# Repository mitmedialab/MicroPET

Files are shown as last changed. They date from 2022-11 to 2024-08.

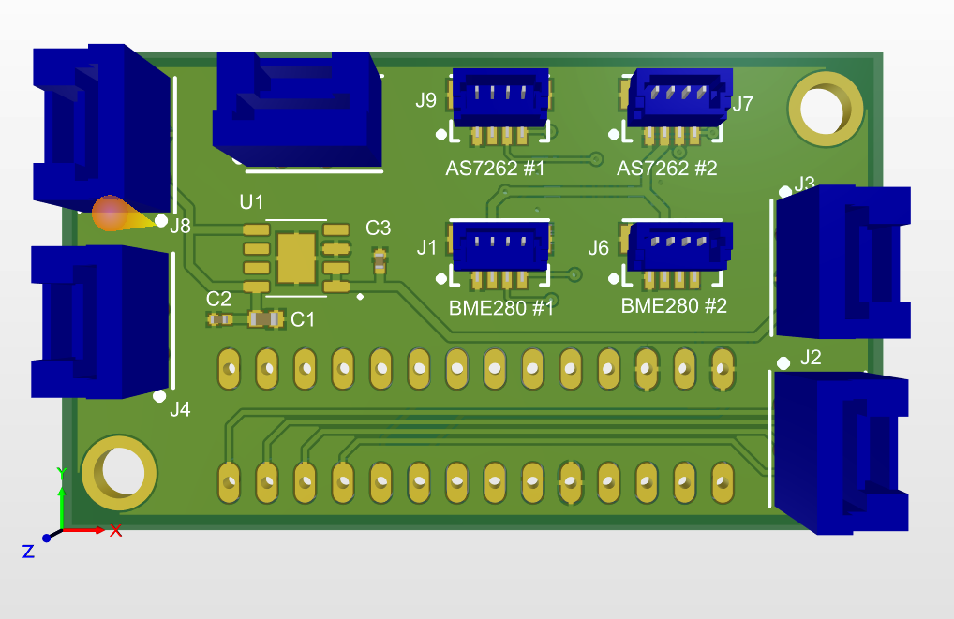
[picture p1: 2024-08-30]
Electronics/Sensor Board/MicroPET Sensor Board - Rev C - rendering.png

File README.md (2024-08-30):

# MicroPET
###  From Development and flight-testing of a modular autonomous cultivation system for biological plastics upcycling aboard the International Space Station

Xin Liu1*, Pat Pataranutaporn1*, Benjamin Fram2, Allison Z. Werner3*, Sunanda Sharma5, Nicholas P. Gauthier4, Erika Erickson3, Patrick Chwalek1, Kelsey J. Ramirez3, Morgan A. Ingraham3, Natasha P. Murphy3, Krista A Ryon6, Braden T Tierney6, Gregg T. Beckham3, Christopher E. Mason7, Ariel Ekblaw1

[1] MIT Media Lab	, Massachusetts Institute of Technology, Cambridge, MA 
[2] Harvard Medical School, Department of Systems Biology, Boston, MA 
[3] Renewable Resources and Enabling Sciences Center, National Renewable Energy Laboratory, Golden, CO 
[4] Department of Data Sciences, Dana-Farber Cancer Institute, Boston, MA
[5] Space Exploration Initiative, Massachusetts Institute of Technology, Cambridge, MA
[6] Weill Cornell Medical College, Cornell University, New York, NY
[7] Department of Physiology and Biophysics, Weill Cornell Medicine, New York, NY

Correspondence: xxxxxxin@mit.edu, patpat@mit.edu, allison.werner@nrel.gov

### Abstract
Cultivation of microorganisms in space has enormous potential to enable in-situ resource utilization (ISRU), but spaceflight infrastructure for growing microorganisms without resource-intensive astronaut support is lacking. Here, we develop and validate an autonomous payload, termed the Modular Open Biological Platform (MOBP), for enzymatic reactions and microbial cultivation with fully programmable serial passaging and sample preservation. The MOBP is a compact, modular bioreactor system that allows for automatic media transfers and precise data monitoring from integrated sensors. The payload enables serial sample collection and storage for terrestrial analysis, including RNA and DNA sequencing and proteomics. We designed two experiments for validation of the MOBP aboard the International Space Station (ISS) with the application of upcycling the ubiquitous plastic poly(ethylene terephthalate) (PET). In the enzymatic experiment, PET is depolymerized by the enzyme PETase to terephthalate (TPA), which can then be polymerized back into virgin quality PET. In the cell-based experiment, TPA is converted to β-ketoadipate (βKA) by an engineered Pseudomonas putida KT2440 bacterium. βKA can be polymerized into a nylon-6,6 analog with improved properties for use in the production of a variety of materials, including high-performance textiles and molded parts including air intake manifolds, electro-insulation elements and hinges, thus demonstrating plastics upcycling. We posit our modular open system will enable increased realization of synthetic biology experiments and applications in spaceflight that will ultimately enable ISRU and plastics upcycling during space travel.

### Keywords
In-situ resource utilization, plastics upcycling, biomanufacturing

### Repository
All code and resources for the MOBP (Modular Open Biological Platform) are available in this GitHub repository. This includes:
- Teensy Launch Code: Teensyduino code to operate MicroPET payload
- Simulation: simulating liquid operation for MicroPET payload
- 3D printing files for the MOBP hardware
- Electronic files for the MOBP

You can access and download all these resources directly from this repository.

# Teensy Launch Code
The code provided is for a MicroPET payload using a Teensyduino microcontroller. The code includes several libraries and defines multiple functions and variables for controlling and managing the payload's experiments and sensors.

The code starts by including various libraries such as TimeLib, TimeAlarms, Wire, SPI, Adafruit_Sensor, Adafruit_BME280, Adafruit_AS726x, Adafruit_MCP23X17, and RTClib. These libraries are used to interface with different sensors and modules.

Next, there are function prototypes for 26 different experiment days, numbered from day_1 to day_26. These functions are used to execute specific experiments on each day of the payload's operation.

The experimentArray is an array of function pointers that stores the addresses of each experiment function. This allows the code to easily access and execute the desired experiment based on the current day.

The code then defines various pin mappings and addresses for different components connected to the Teensyduino, such as the base board connectors and MCP23X17 GPIO expanders.

Further in the code, there are implementations of functions for controlling motors, switching IO ports, moving liquids between different chambers, switching collection bags, taking sensor data, initializing the SD card, and saving data to files.

The loop function of the code waits for a serial start command from the user to begin the payload's experiments. Once the command is received, the code calls the day_1 function to start the first day's experiment. After each experiment, the code sets the next alarm to schedule the next experiment based on the defined delay between experiments.

There is also a function for recovering the system after an unscheduled power loss. This function checks if the system was interrupted during an experiment or if it was off for a longer time than the experiment interval. If it can resume the experiment, it sets the next alarm and continues from where it left off.

The rest of the code includes functions for reading data from sensors, saving sensor data to a file, and initializing the SD card and experimental log file. Overall, the code provides the functionality for controlling and managing the MicroPET payload, executing different experiments, collecting sensor data, and saving data to files.

### Base Board Connection
The base board connections are as follows:
- E1VA + E1PA - J10
- E1VB + E1PB - J09
- E2VA + E2PA - J12
- E2VB + E2PB - J11
- The valve board connector J1-6 are the same on the base board

### Dependencies
The code depends on the following libraries:
- TimeLib.h
- TimeAlarms.h
- Wire.h
- SPI.h
- Adafruit_Sensor.h
- Adafruit_BME280.h
- Adafruit_AS726x.h
- Adafruit_MCP23X17.h
- RTClib.h
- SD.h

### Experiment Protocols
The code defines the following experiment protocols:
- day_1()
- day_2()
- day_3()
- day_4()
- ...
- day_26()

The experiment functions are stored in an array called `experimentArray`, which is of size `TOTAL_EXPERIMENTS`.

### Global Variables
- `rtc`: RTC_PCF8523 object to interface with the RTC module.
- `experimentIndex`: uint16_t variable to keep track of the current experiment index.
- `delayTime`: unsigned long variable to store the delay time between experiments.
- `sensorValues`: uint16_t array to store the sensor values read from the AS726x sensor.
- `myFile`: File object to store data in a file.
- `expLogFile`: File object to store experimental log data in a file.
- `systemStateStructVar`: systemStateStruct object to store the system state.

### Main Functions
- `setup()`: Initializes the program by initializing variables, setting up the RTC, SD card, and IO ports, and setting the first alarm.
- `loop()`: Loops indefinitely, checking for a start command via serial communication and executing the corresponding experiment.
- `rtcInit()`: Initializes the RTC module by checking for RTC availability, adjusting the time if necessary, and calibrating the RTC.
- `grabStateFromSD()`: Reads the system state from the SD card if it exists, and returns true if successful.
- `saveStateToSD()`: Saves the system state to the SD card.
- `checkForStartSerialCommand()`: Checks for a start command via serial communication and returns true if it is received.
- `recoverSystemStart()`: Resumes system operation after an unscheduled power loss by checking for hard faults and setting up timers.
- `setNextAlarm()`: Sets the next alarm based on the current experiment index.
- `moveLiquid()`: Moves liquid from one location to another based on the experiment, origin, target, and liquid volume.
- `switchCollection()`: Switches the collection bag for a particular experiment.
- `Taking_Sensor_Data()`: Takes sensor data by reading temperature and spectral values from the BME280 and AS726x sensors.
- `saveExperimentalLog()`: Saves an experimental log message to the experiment log file.
- `init_card()`: Initializes the SD card by checking for availability, opening the save file, and writing the header if necessary.
- `initExpLogFile()`: Initializes the experiment log file by opening it and writing the header.
- `motorSensorBrdCtrl()`: Controls the motors on the sensor board based on the motor number and direction.

### Helper Functions
- `digitalClockDisplay()`: Displays the current time on the serial monitor.
- `printDigits()`: Prints digits with leading zeroes if necessary.
- `tmConvert_t()`: Converts a specified date and time to a time_t format.

### Contact
For questions or further information, please contact the corresponding authors listed above.

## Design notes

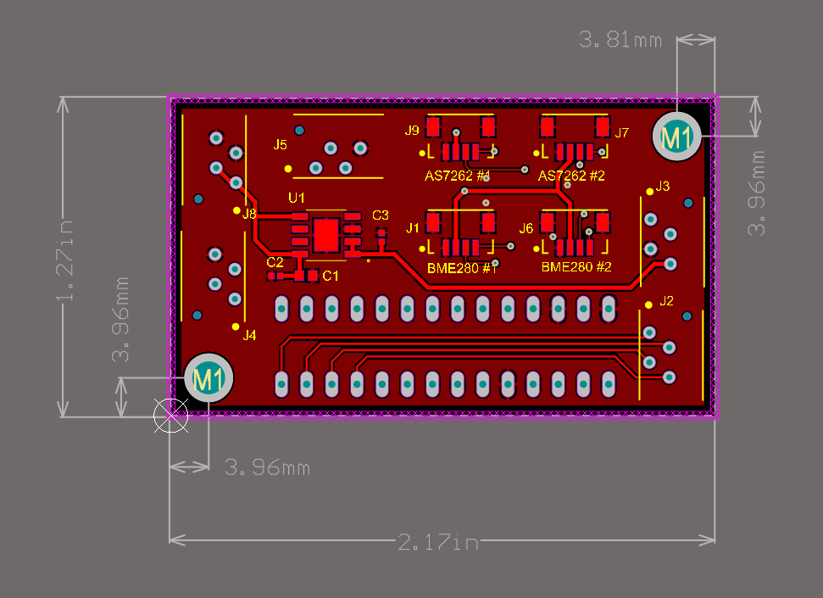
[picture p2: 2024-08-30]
Electronics/Sensor Board/MicroPET Sensor Board - Rev C.png

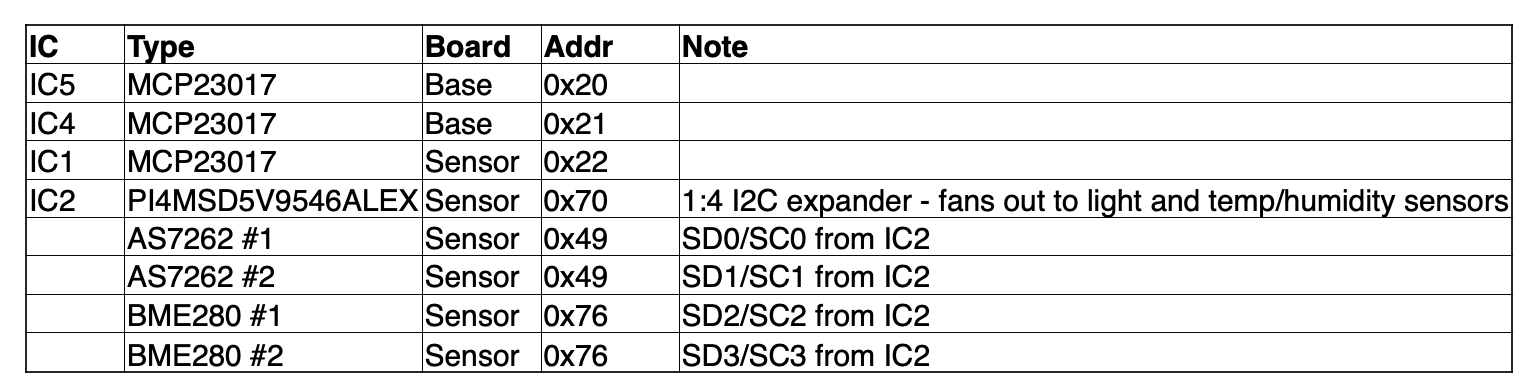
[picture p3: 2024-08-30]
Electronics/Sensor Board/MicroPET Sensor Board - Rev C - IO ports.png

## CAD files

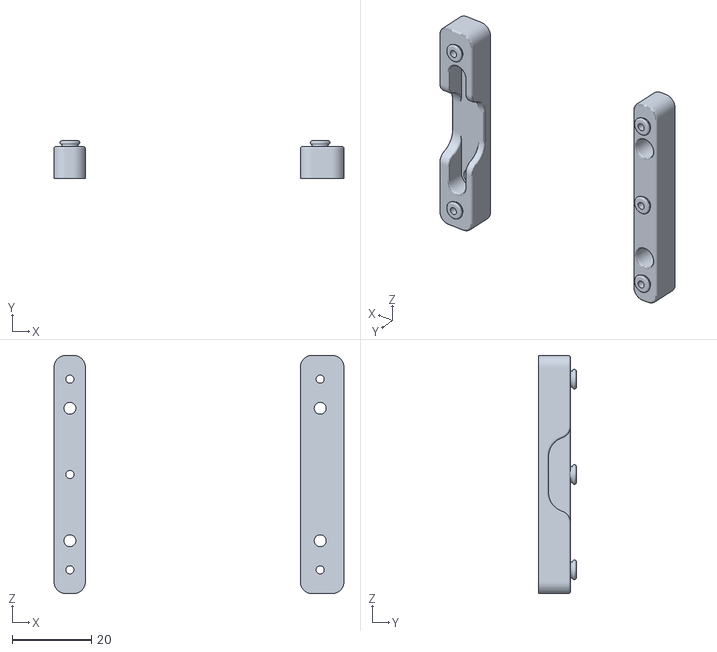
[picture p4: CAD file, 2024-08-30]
3D Printing/Bag Holder Prints/micropet_enclosure_print_001.STL
73.0 x 9.50 x 60.0

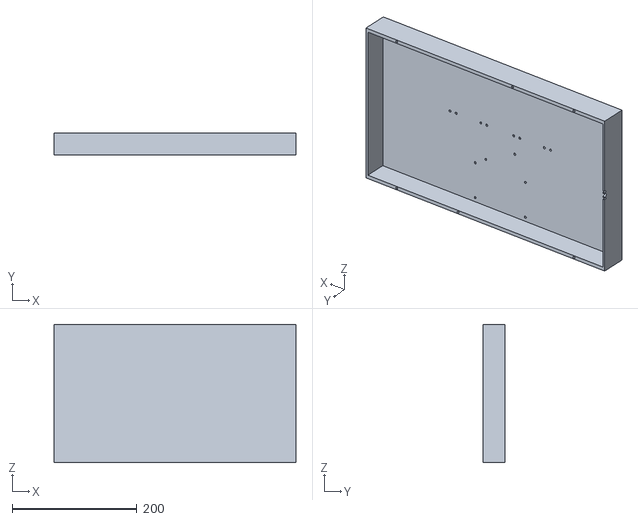
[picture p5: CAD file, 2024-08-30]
3D Printing/MicroPET_top_enclosure_twocells.stl
388.6 x 36.1 x 222.0

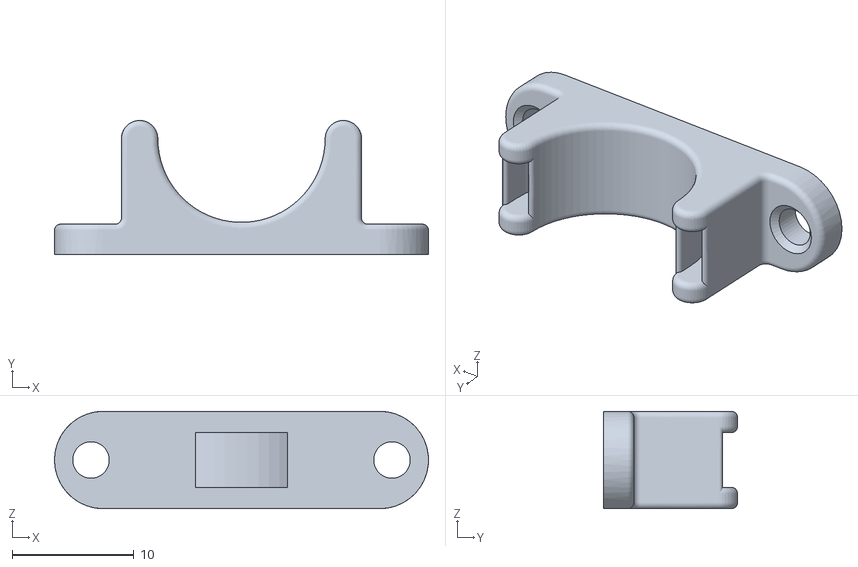
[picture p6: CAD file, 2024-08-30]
3D Printing/Bag Holder Prints/micropet_enclosure_print_004.STL
30.8 x 11.0 x 8.00

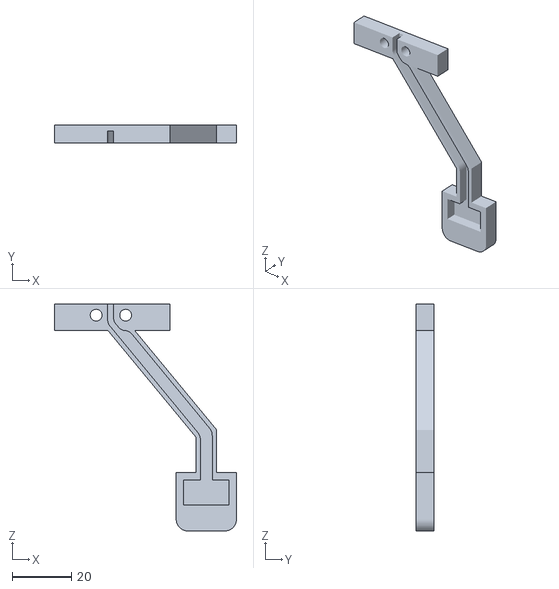
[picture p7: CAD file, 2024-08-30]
3D Printing/BioCell LED holder v5.stl
61.7 x 6.00 x 76.9

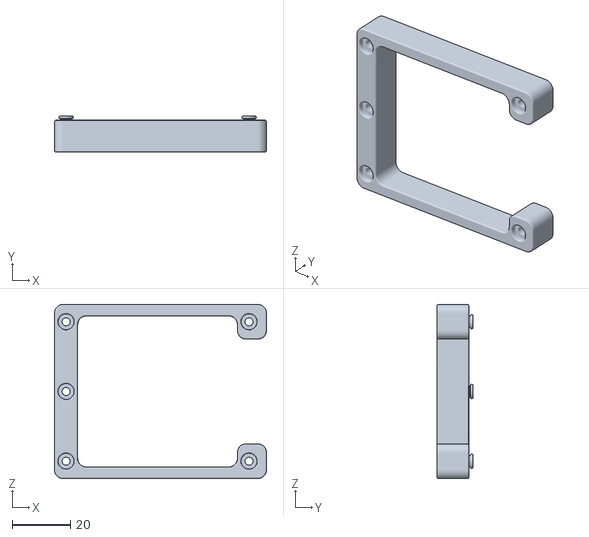
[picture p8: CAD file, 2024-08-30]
3D Printing/Bag Holder Prints/micropet_enclosure_print_002.STL
73.0 x 12.5 x 60.0

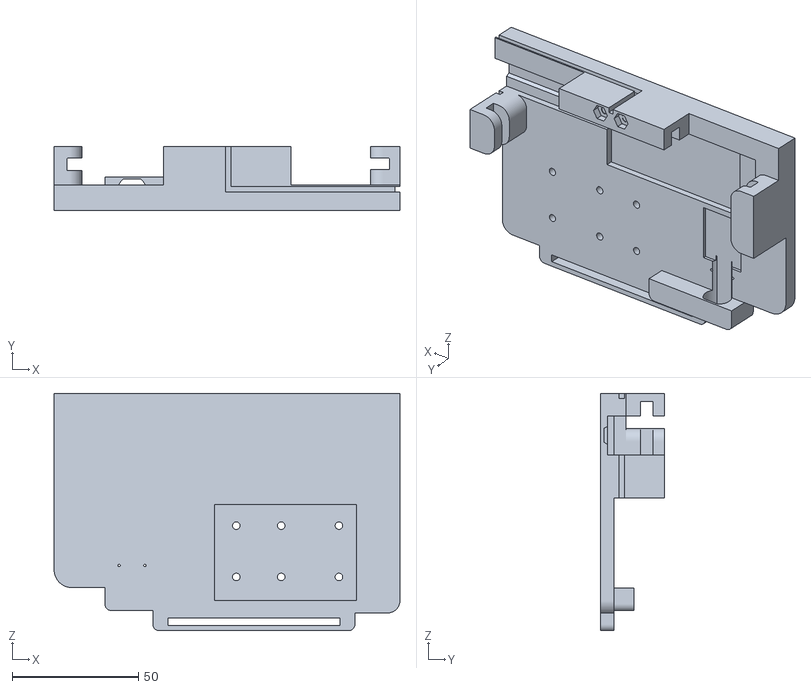
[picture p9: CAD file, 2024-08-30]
3D Printing/BioCell Final Print v5.stl
137.0 x 25.5 x 94.0

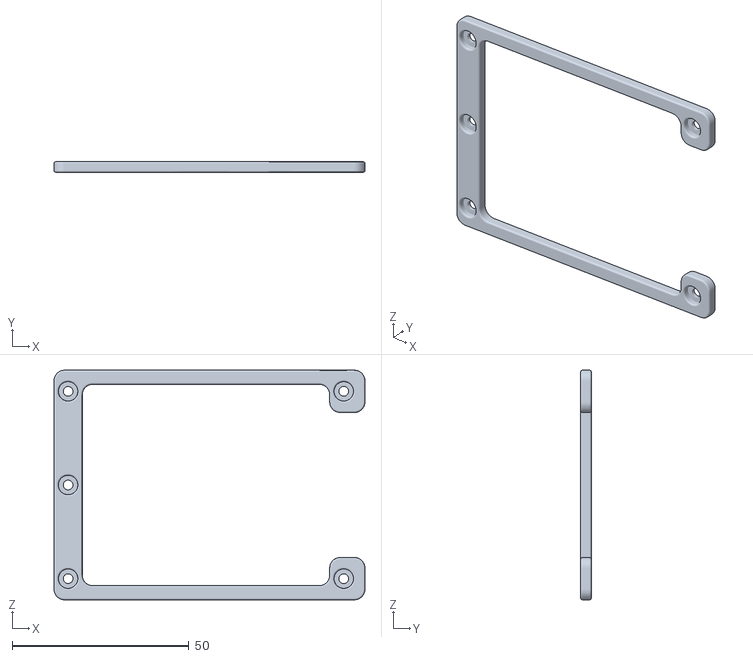
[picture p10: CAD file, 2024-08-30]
3D Printing/Bag Holder Prints/micropet_enclosure_print_009.STL
88.0 x 3.00 x 65.0

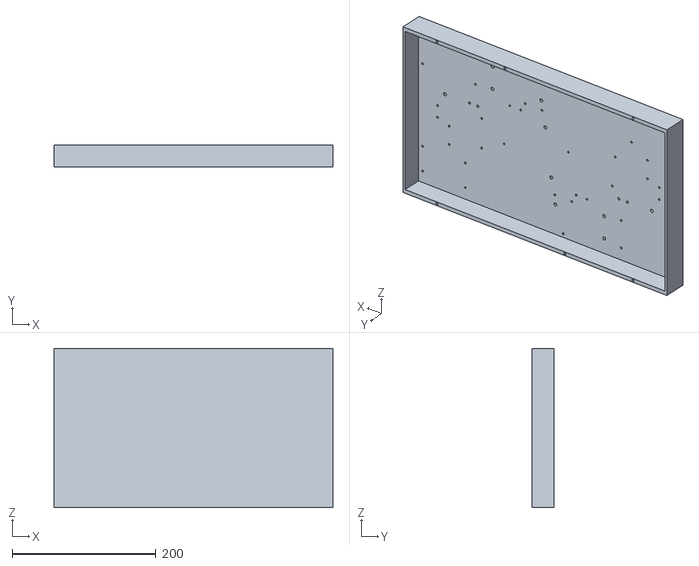
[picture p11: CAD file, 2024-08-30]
3D Printing/MicroPET_base_enclosure_01 v2.stl
388.6 x 30.4 x 222.0

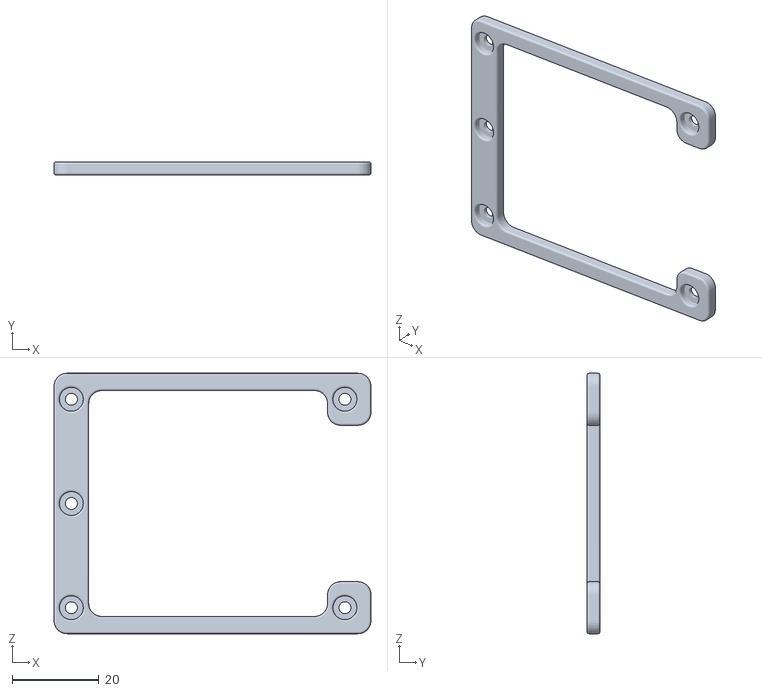
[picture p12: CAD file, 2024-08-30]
3D Printing/Bag Holder Prints/micropet_enclosure_print_003.STL
73.0 x 3.00 x 60.0

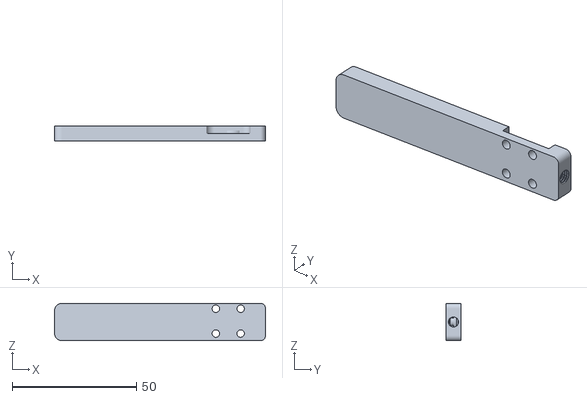
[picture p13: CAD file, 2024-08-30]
3D Printing/Revival Chip.stl
85.0 x 6.00 x 15.0

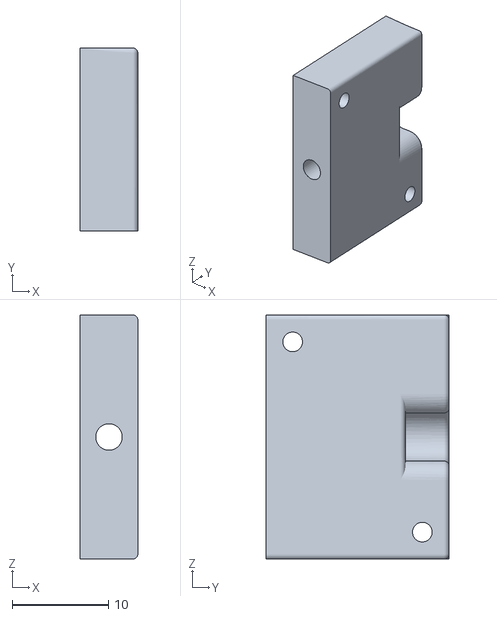
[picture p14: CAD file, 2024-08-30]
3D Printing/Bag Holder Prints/micropet_enclosure_print_006.STL
6.00 x 19.1 x 25.4

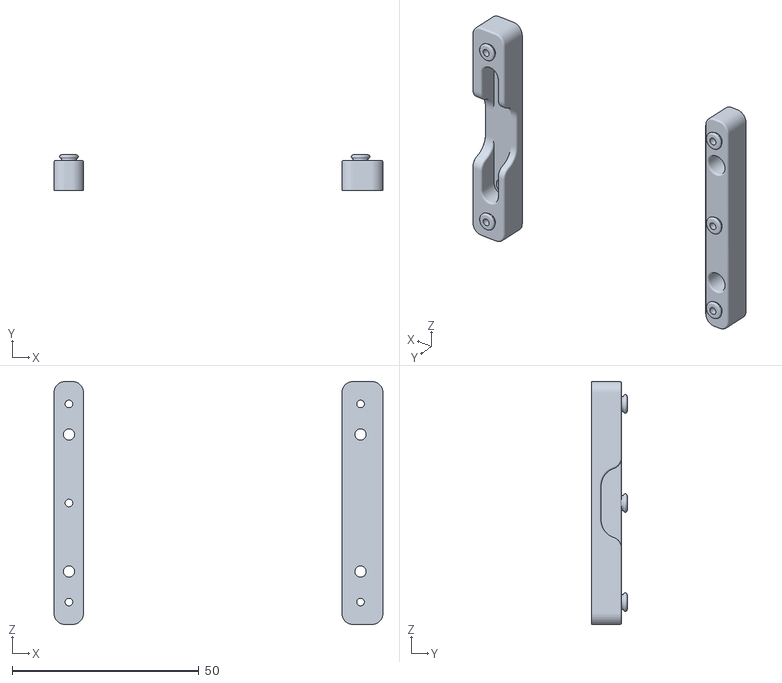
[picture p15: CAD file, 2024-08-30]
3D Printing/Bag Holder Prints/micropet_enclosure_print_007.STL
88.0 x 9.50 x 65.0

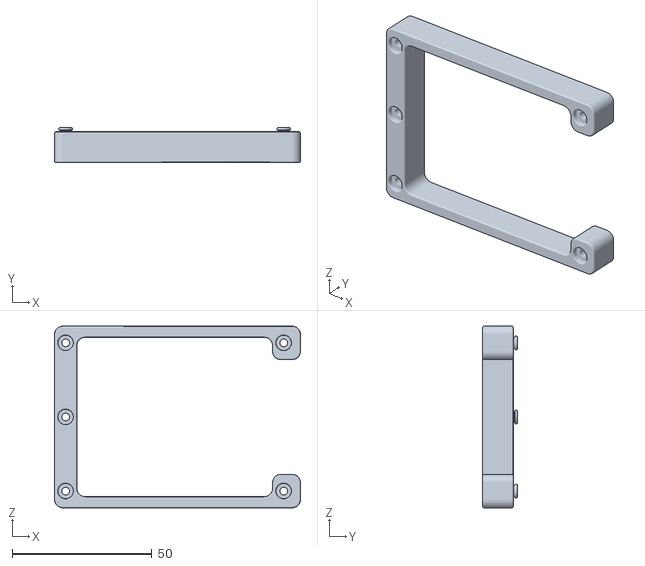
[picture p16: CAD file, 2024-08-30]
3D Printing/Bag Holder Prints/micropet_enclosure_print_008.STL
88.0 x 12.5 x 65.0

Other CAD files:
3D Printing/Bag Holder Prints/micropet_enclosure_print_005.STL
3D Printing/Bag Holder Prints/micropet_enclosure_print_010.STL

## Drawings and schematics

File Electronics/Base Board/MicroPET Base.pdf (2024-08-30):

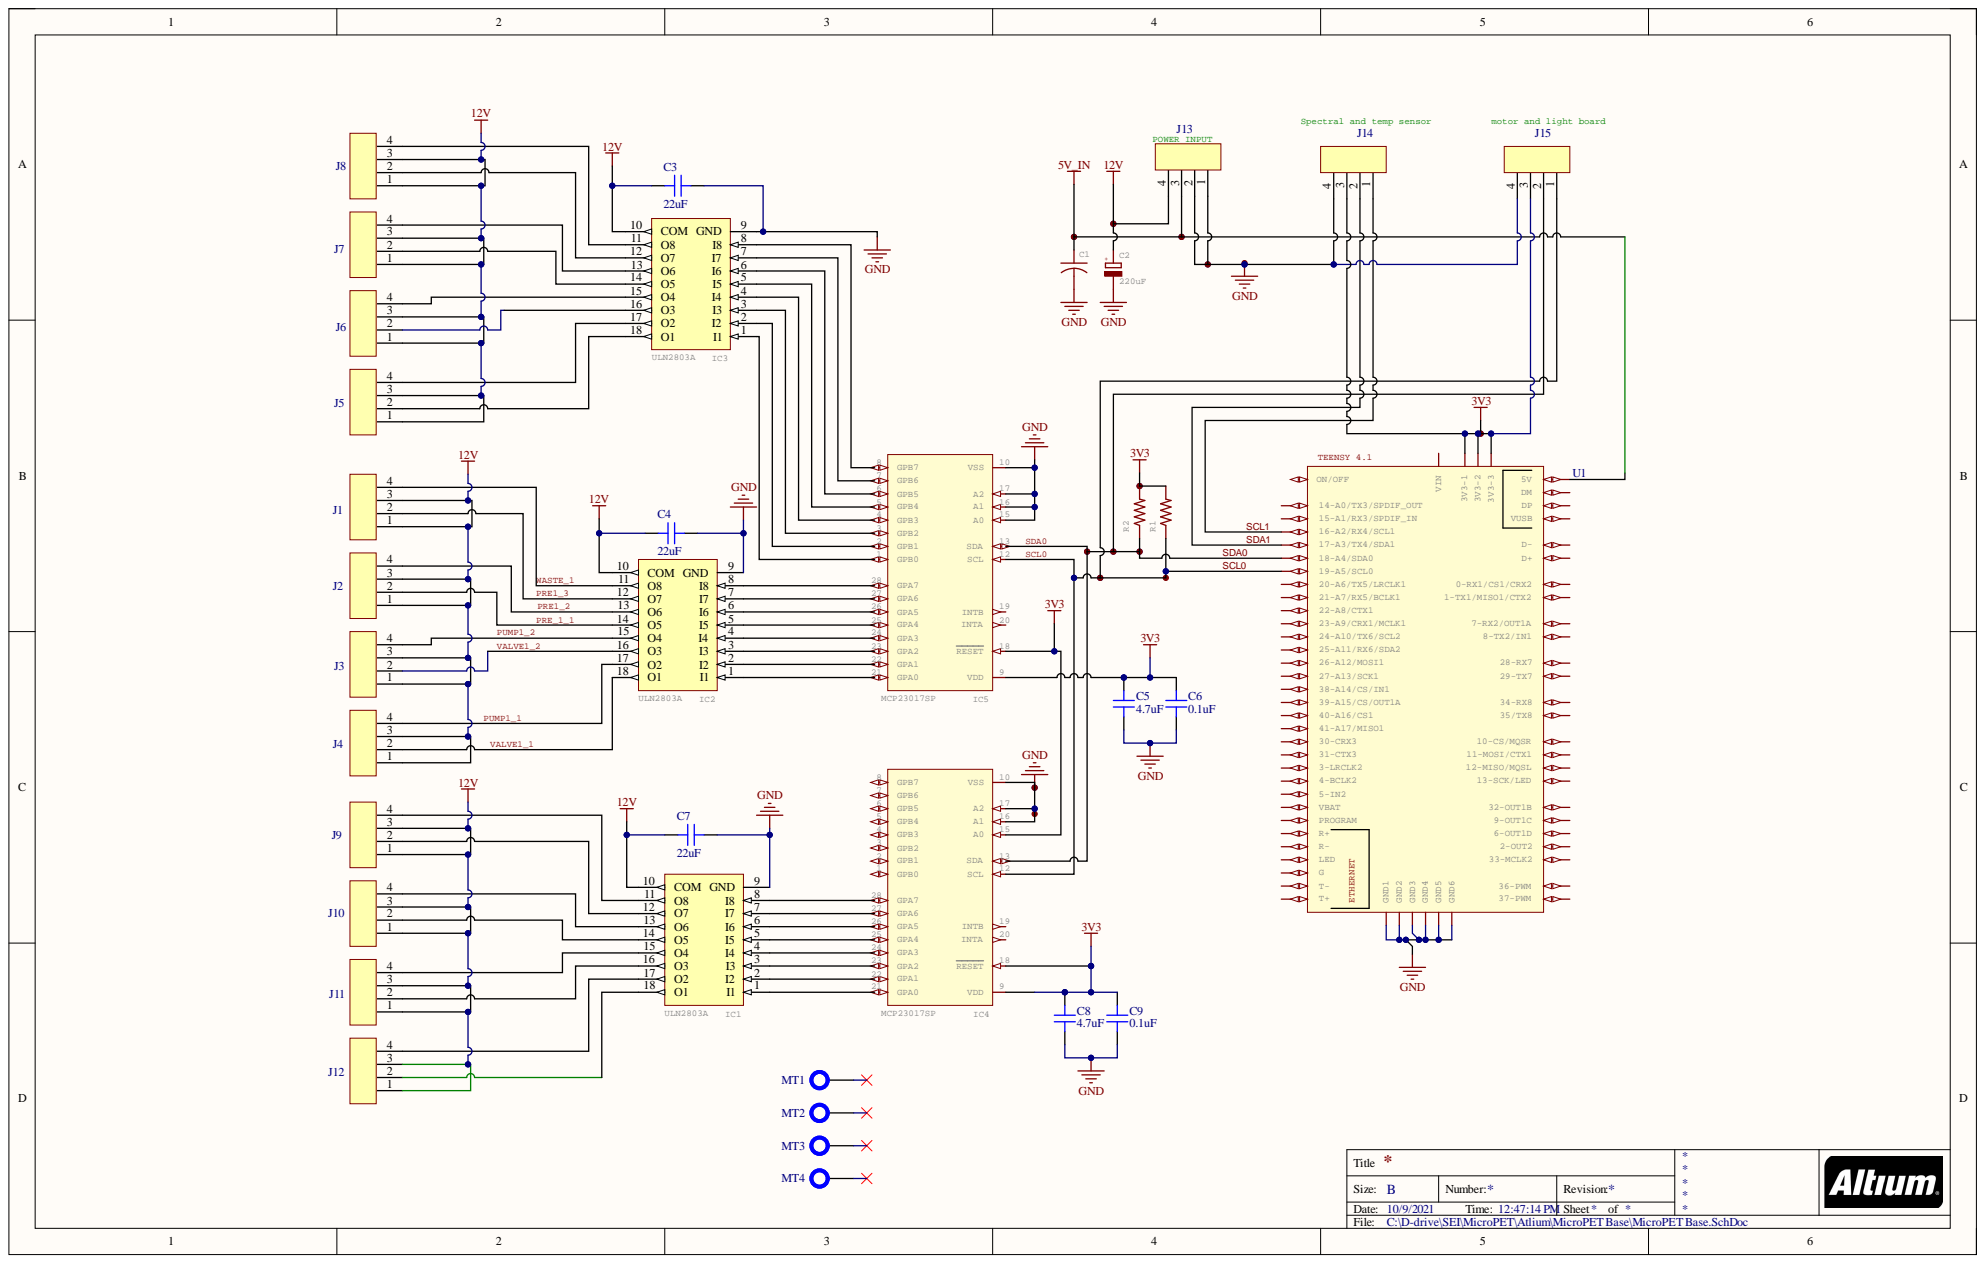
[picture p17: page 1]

3 | 12V

3 | WASTE_1
2 | | 3V3

3 | VALVE1_1

Title * | * * * * *

Size: B | Number: * | Revision: *
Date: 10/9/2021 Time: 12:47:14 PM | | Sheet * of *

C:\D-drive\SEI\MicroPET\Atlium\MicroPETBase\MicroPETBase.SchDoc

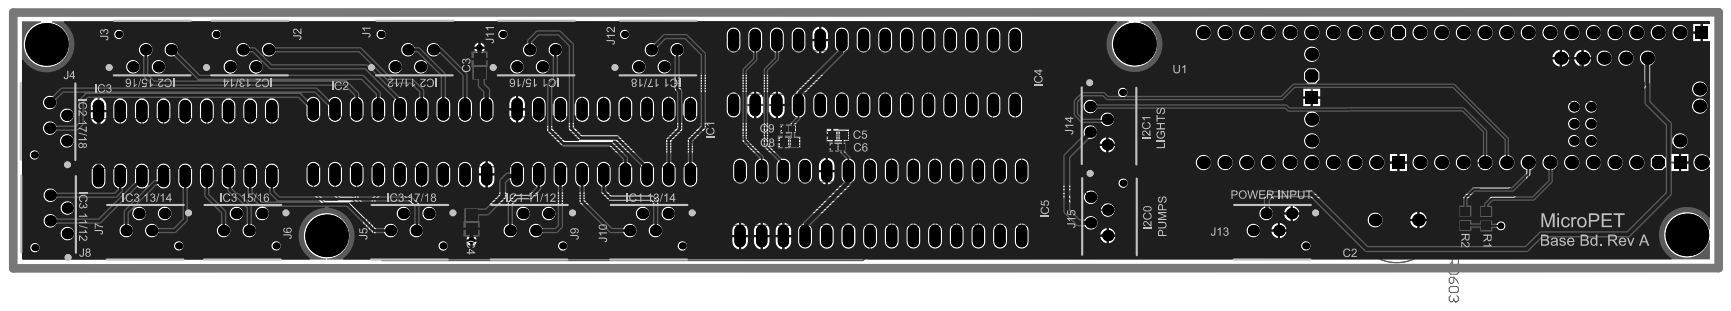
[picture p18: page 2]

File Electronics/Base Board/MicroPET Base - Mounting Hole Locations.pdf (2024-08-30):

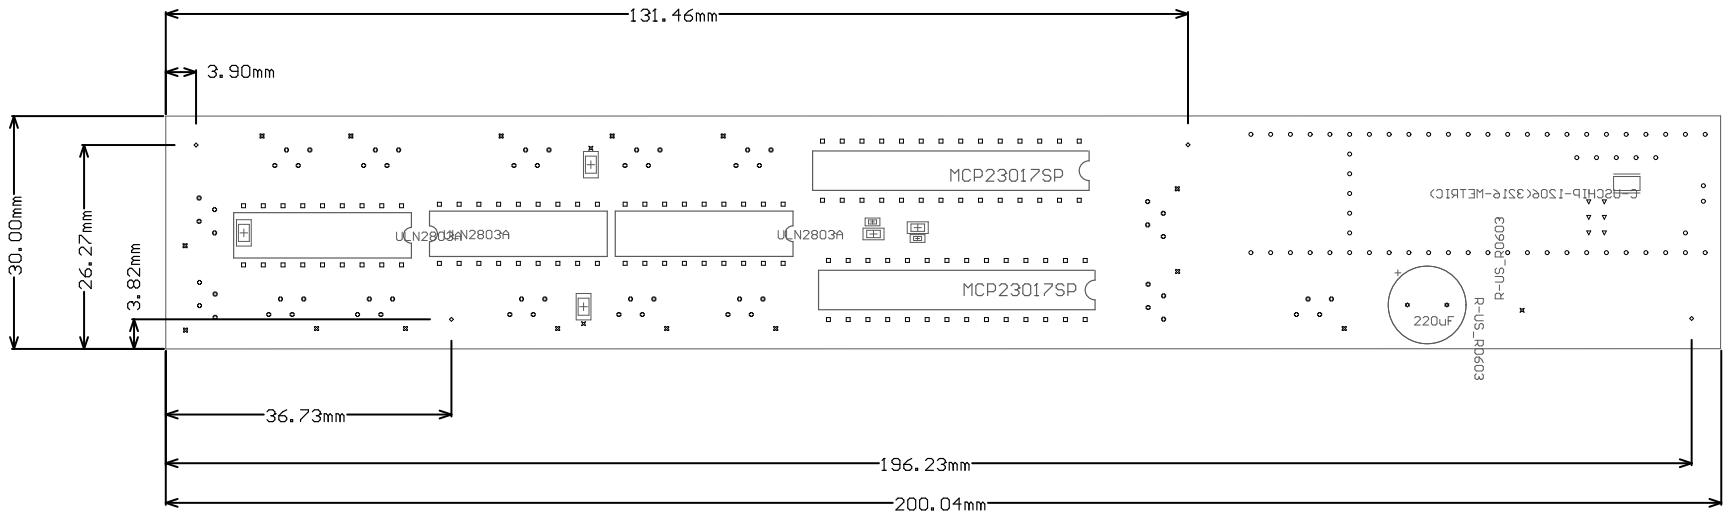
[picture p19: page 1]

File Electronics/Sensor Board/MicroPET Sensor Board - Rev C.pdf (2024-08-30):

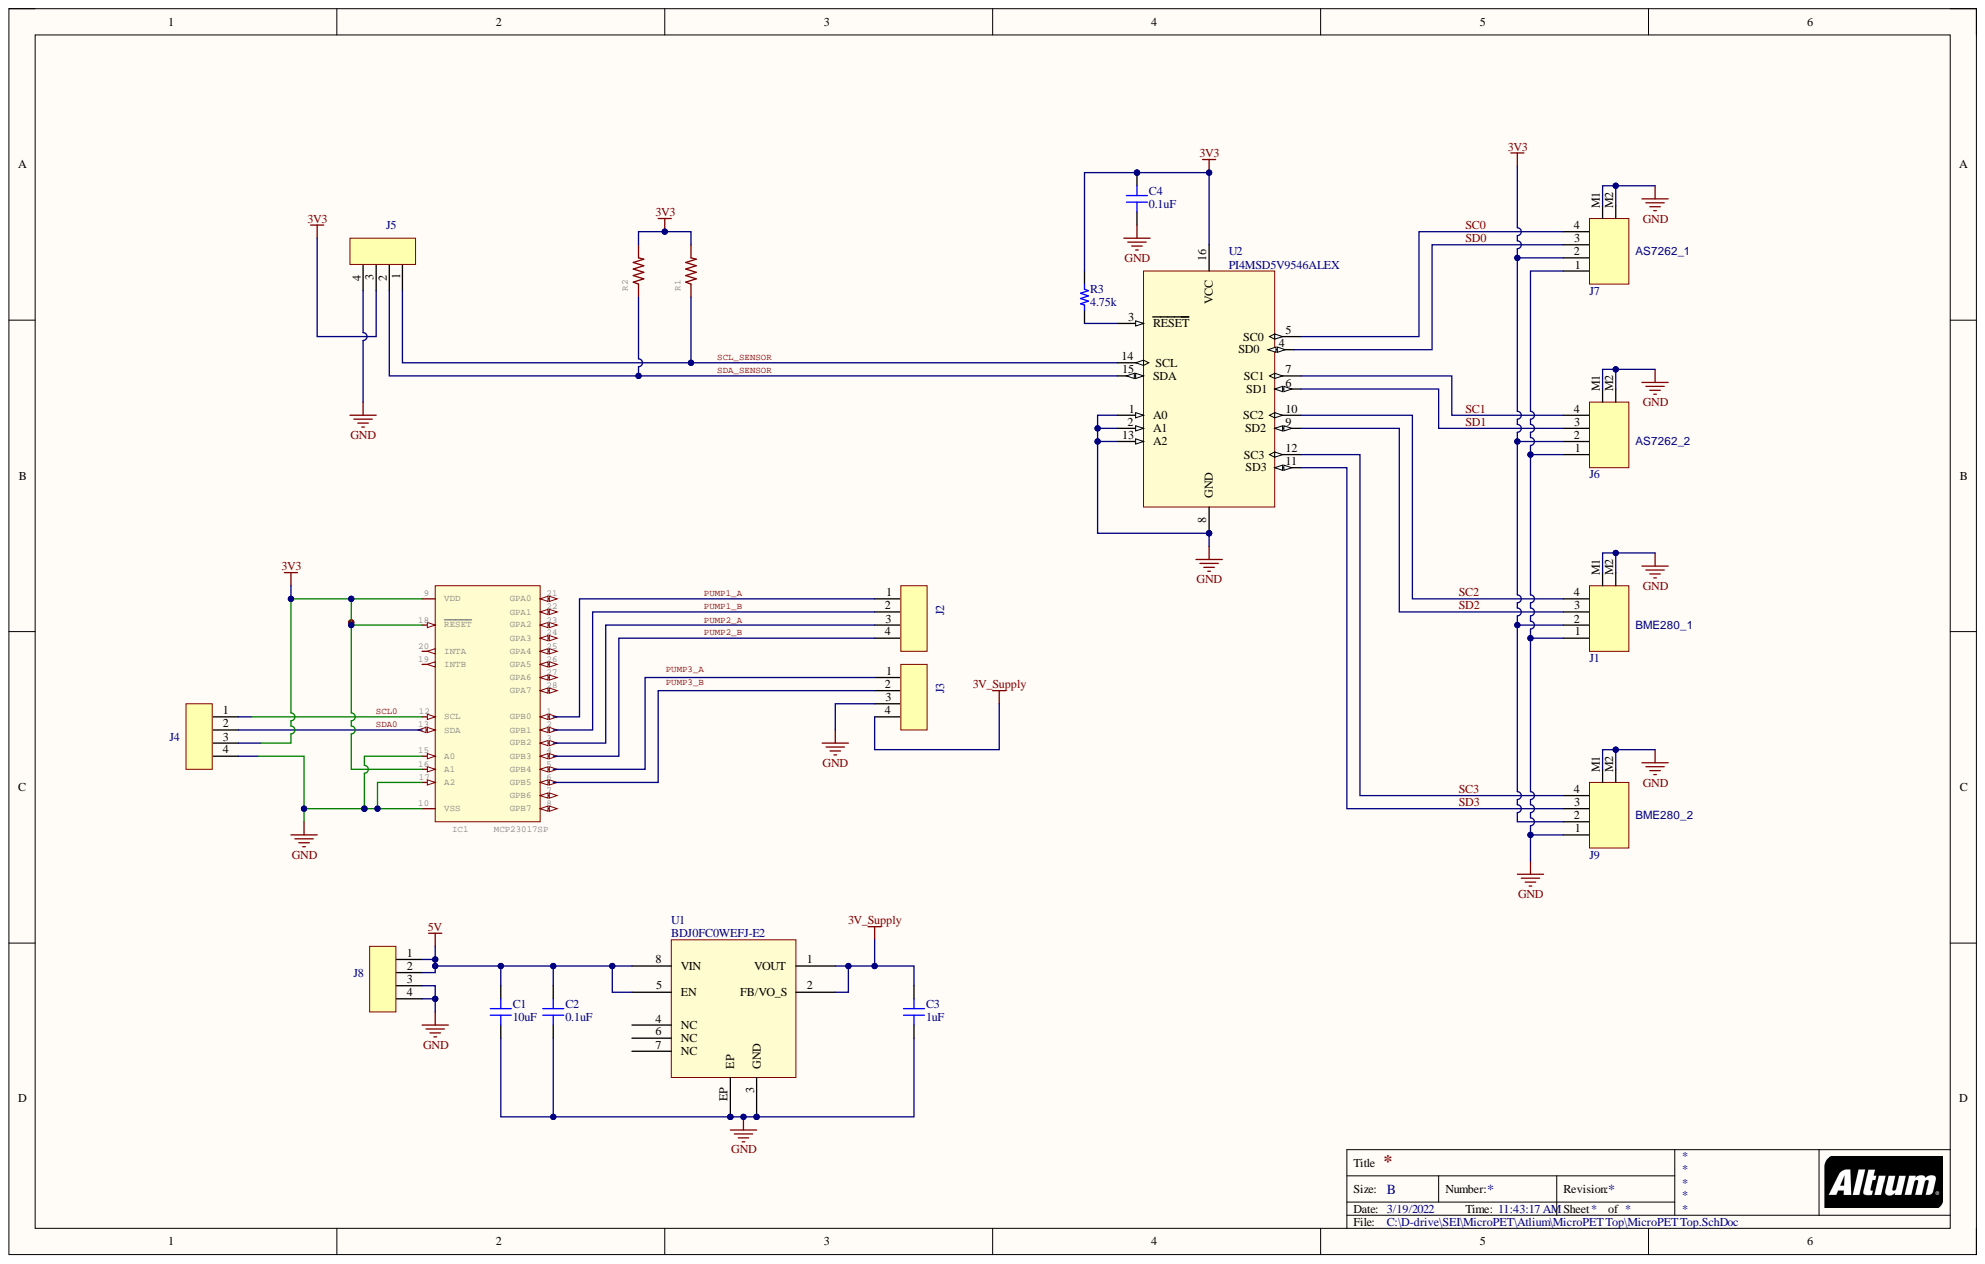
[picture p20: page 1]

RESE A 15 T SD 0 L 14 SC SD SD 1 2 13 SD 2 A SD 3 | 4 SC0

4321 SDA0 | SDA 13 | 2

A2 17 | 6
VSS 10 | 7 U 1 3V_Suppl

Si z e : B | N umber : * | Revi s i on: *
Dat e : 3/19/ 20 2 2 Ti me: 11:43:17 AM | | Sheet * of *

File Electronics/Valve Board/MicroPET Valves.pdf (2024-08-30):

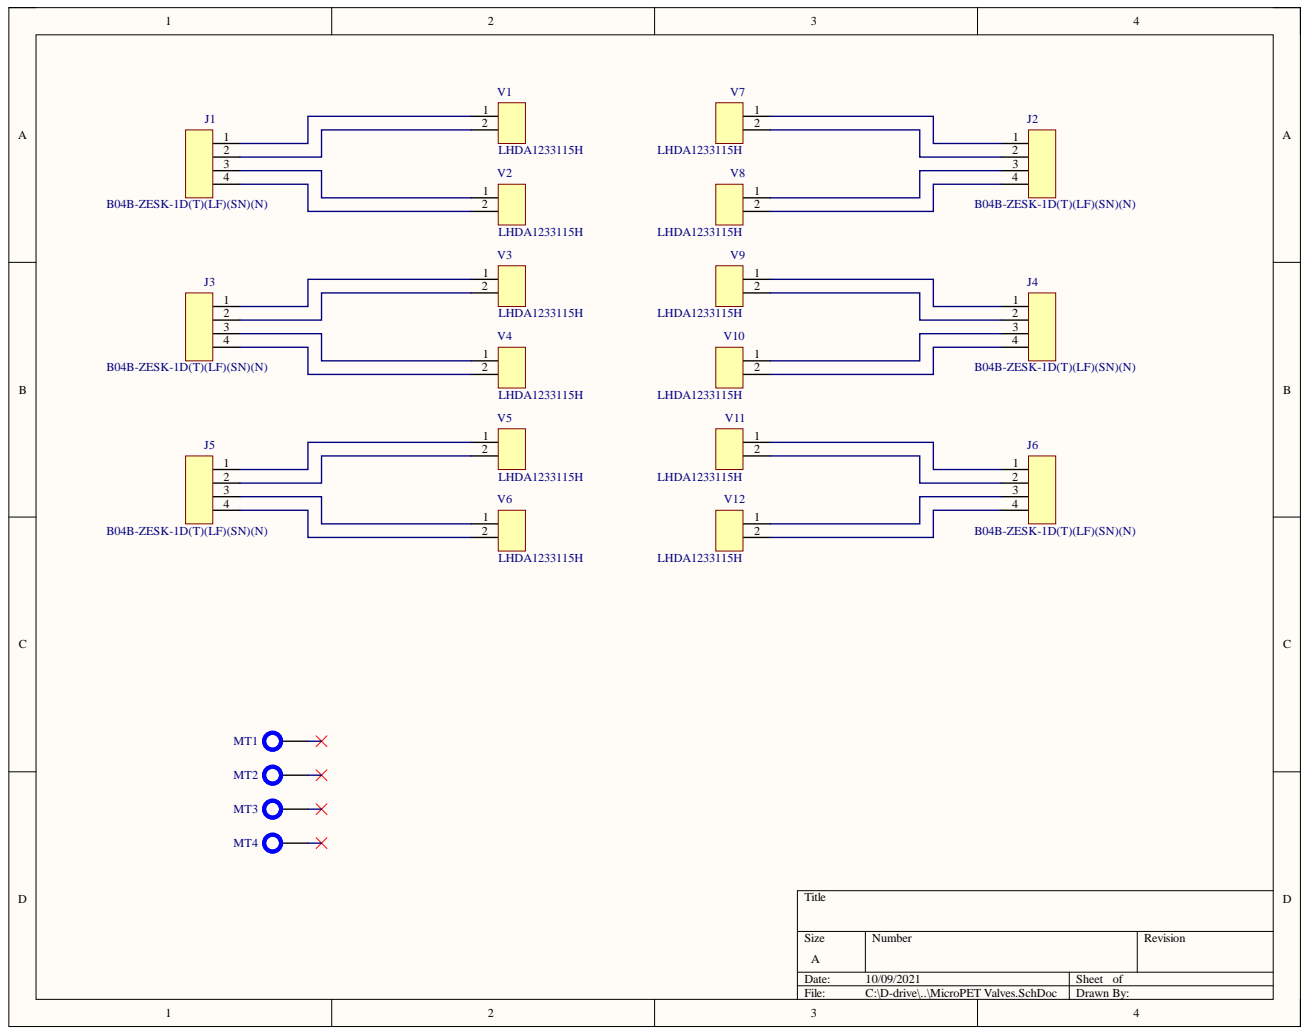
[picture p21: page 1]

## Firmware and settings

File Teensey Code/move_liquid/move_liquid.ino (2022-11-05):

#include <Adafruit_MCP23X17.h>

#define MCP_ADDR0 0x20  // IC5 on base board
#define MCP_ADDR1 0x21  // IC4 on base board
#define MCP_ADDR2 0x22  // IC1 on sensor board

//revivial pump
enum motion { forward, reverse, halt };
#define PUMP1_A 8
#define PUMP1_B 9
#define PUMP2_A 10
#define PUMP2_B 11
#define PUMP3_A 12
#define PUMP3_B 13

#define LED 13

// Double check these pin assignments
#define GPA0 0
#define GPA1 1
#define GPA2 2
#define GPA3 3
#define GPA4 4
#define GPA5 5
#define GPA6 6
#define GPA7 7

#define GPB0 8
#define GPB1 9
#define GPB2 10
#define GPB3 11
#define GPB4 12
#define GPB5 13
#define GPB6 14
#define GPB7 15

#define experimentOne 1
#define experimentTwo 2

#define e_buffer 0
#define enzyme 1
#define chamberA 2
#define media 3
#define chamberB 4

#define waste 0
#define preservativeOne 1  
#define preservativeTwo 2
#define preservativeThree 3
#define preservativeFour 4
#define preservativeFive 5


Adafruit_MCP23X17 mcp0;
Adafruit_MCP23X17 mcp1;
Adafruit_MCP23X17 mcp2;

typedef enum {
  // MCP0 - IC5 on base board
  BASEBD_J4_PIN2 = 0,
  BASEBD_J4_PIN4,
  BASEBD_J3_PIN2,
  BASEBD_J3_PIN4,
  BASEBD_J2_PIN2,
  BASEBD_J2_PIN4,
  BASEBD_J1_PIN2,
  BASEBD_J1_PIN4,
  BASEBD_J5_PIN2,
  BASEBD_J5_PIN4,
  BASEBD_J6_PIN2,
  BASEBD_J6_PIN4,
  BASEBD_J7_PIN2,
  BASEBD_J7_PIN4,
  BASEBD_J8_PIN2,
  BASEBD_J8_PIN4,

  // MCP1 - IC4 on base board
  BASEBD_J12_PIN2,
  BASEBD_J12_PIN4,
  BASEBD_J11_PIN2,
  BASEBD_J11_PIN4,
  BASEBD_J10_PIN2,
  BASEBD_J10_PIN4,
  BASEBD_J9_PIN2,
  BASEBD_J9_PIN4,
  
  //MCP2 - IC1 on sensor board
  SENSEBD_J2_PIN1,
  SENSEBD_J2_PIN2,
  SENSEBD_J2_PIN3,
  SENSEBD_J2_PIN4,
  SENSEBD_J3_PIN1,
  SENSEBD_J3_PIN2
} CONN_PIN_T; // Connector and Pin type

#define MCP1_PIN_OFFSET 16
#define MCP2_PIN_OFFSET 16

/****************************************/

boolean switch_conn_pin(CONN_PIN_T conn_pin, byte level)
{
  if((level != HIGH) && (level != LOW)) {
    return false;
  }
  
  if(conn_pin <= BASEBD_J8_PIN4) {
    mcp0.digitalWrite(conn_pin, level);
  } else if(conn_pin <= BASEBD_J9_PIN4) {
    mcp1.digitalWrite((conn_pin - MCP1_PIN_OFFSET), level);
  } else if(conn_pin <= SENSEBD_J3_PIN2) {
    mcp2.digitalWrite((conn_pin - MCP2_PIN_OFFSET), level);
  } else {
    return false;
  }

  return true;
}

int stop_move;

void setup() {
   Serial.begin(9600);
 // while (!Serial);
 // Serial.println("MCP23xxx Blink Test!");

  pinMode(LED, OUTPUT);

  // uncomment appropriate mcp.begin
  if (!mcp0.begin_I2C(MCP_ADDR0)) {
    Serial.println("Error initializing chip 0.");
   // while (1);
  }

  if (!mcp1.begin_I2C(MCP_ADDR1)) {
    Serial.println("Error initializing chip 1.");
    //while (1);
  }

  // IC5 on base board
  mcp0.pinMode(GPA0, OUTPUT);
  mcp0.pinMode(GPA1, OUTPUT);
  mcp0.pinMode(GPA2, OUTPUT);
  mcp0.pinMode(GPA3, OUTPUT);
  mcp0.pinMode(GPA4, OUTPUT);
  mcp0.pinMode(GPA5, OUTPUT);
  mcp0.pinMode(GPA6, OUTPUT);
  mcp0.pinMode(GPA7, OUTPUT);

  mcp0.pinMode(GPB0, OUTPUT);
  mcp0.pinMode(GPB1, OUTPUT);
  mcp0.pinMode(GPB2, OUTPUT);
  mcp0.pinMode(GPB3, OUTPUT);
  mcp0.pinMode(GPB4, OUTPUT);
  mcp0.pinMode(GPB5, OUTPUT);
  mcp0.pinMode(GPB6, OUTPUT);
  mcp0.pinMode(GPB7, OUTPUT);

  // IC4 on base board
  mcp1.pinMode(GPA0, OUTPUT);
  mcp1.pinMode(GPA1, OUTPUT);
  mcp1.pinMode(GPA2, OUTPUT);
  mcp1.pinMode(GPA3, OUTPUT);
  mcp1.pinMode(GPA4, OUTPUT);
  mcp1.pinMode(GPA5, OUTPUT);
  mcp1.pinMode(GPA6, OUTPUT);
  mcp1.pinMode(GPA7, OUTPUT);

 //Revial 
 
   if (!mcp2.begin_I2C(MCP_ADDR2)) {
    Serial.println("Error initializing chip 2.");
 //   while (1);
  }
/*
  // IC1 on sensor board
  mcp2.pinMode(GPB0, OUTPUT);
  mcp2.pinMode(GPB1, OUTPUT);
  mcp2.pinMode(GPB2, OUTPUT);
  mcp2.pinMode(GPB3, OUTPUT);
  mcp2.pinMode(GPB4, OUTPUT);
  mcp2.pinMode(GPB5, OUTPUT);

  Serial.println("Looping...");

*/

    Serial.println("revival pumping...");
    mcp2.pinMode(PUMP1_A, OUTPUT);
    mcp2.pinMode(PUMP1_B, OUTPUT);
    //    mcp.pinMode(PUMP2_A, OUTPUT);
    //    mcp.pinMode(PUMP2_B, OUTPUT);
    mcp2.pinMode(PUMP3_A, OUTPUT);
    mcp2.pinMode(PUMP3_B, OUTPUT);

    // halt both motors upon initialization
    
    motorSensorBrdCtrl(1, halt);
    motorSensorBrdCtrl(3, halt);
    Serial.println("revival pumping halted");
    
int stop_move = 0;



}

void loop() {

  Serial.println("revival pumping...");
  motorSensorBrdCtrl(1, forward);
  delay (5000);
  motorSensorBrdCtrl(1, halt);
  
//Experiment1 liquid system cleaning
// moveLiquid (experimentOne, e_buffer, chamberA, 50);
// moveLiquid (experimentOne, enzyme, chamberA, 5000);
// moveLiquid (experimentOne, media, chamberB, 5000);

//Experiment2 liquid system cleaning
// moveLiquid (experimentTwo, e_buffer, chamberA, 5000);
// moveLiquid (experimentTwo, enzyme, chamberA, 5000);
// moveLiquid (experimentTwo, media, chamberB, 5000);

//Experiment2 collection 
/*
switchCollection(experimentTwo, preservativeTwo);
delay (3000);
switchCollection(experimentTwo, preservativeThree);
delay (3000);
switchCollection(experimentTwo, preservativeFour);
delay (3000);

  Serial.println("revival pumping...");
  motorSensorBrdCtrl(1, forward);
  delay (5000);
  motorSensorBrdCtrl(1, halt);
  
  /*   
  motorSensorBrdCtrl(3, forward);
  delay (500); //8-9 times for a 10ML revival from the big media bag
  motorSensorBrdCtrl(3, halt);
  
  /*
   * 
   * moveLiquid (experimentOne, media, chamberB, 5000);
   switchCollection(experimentOne, preservativeOne);
  moveLiquid (experimentOne, media, chamberB, 5000);
   switchCollection(experimentOne, preservativeTwo);
  moveLiquid (experimentOne, media, chamberB, 5000);
  switchCollection(experimentOne, preservativeThree);
  moveLiquid (experimentOne, media, chamberB, 5000);
  switchCollection(experimentOne, preservativeFour);
  moveLiquid (experimentOne, media, chamberB, 5000);
  switchCollection(experimentOne, waste);
  moveLiquid (experimentOne, media, chamberB, 5000);
  
  delay(5000);
  moveLiquid (experimentOne, media, chamberB, 5000);
  delay(5000);
  switchCollection(experimentOne, preservativeTwo);
  moveLiquid (experimentOne, media, chamberB, 5000);
  delay(5000);
  switchCollection(experimentOne, preservativeThree);
  moveLiquid (experimentOne, media, chamberB, 5000);
  delay(5000);
  switchCollection(experimentOne, preservativeFour);
  moveLiquid (experimentOne, media, chamberB, 5000);
  delay(5000);

 */
 

}

/* Function to control motors on sensor board */
/* Input: (1) motor_num is either 1 or 3
 *        (2) dir is either forward, reverse, or halt
 */
void motorSensorBrdCtrl(uint8_t motor_num, motion dir){
  if(motor_num == 1){
    if(dir == forward){
      mcp2.digitalWrite(PUMP1_A, HIGH);
      mcp2.digitalWrite(PUMP1_B, LOW);
    }else if(dir == reverse){
      mcp2.digitalWrite(PUMP1_A, LOW);
      mcp2.digitalWrite(PUMP1_B, HIGH);
    }else if(dir == halt){
      mcp2.digitalWrite(PUMP1_A, LOW);
      mcp2.digitalWrite(PUMP1_B, LOW);
    }
  }else if(motor_num == 3){
    if(dir == forward){
      mcp2.digitalWrite(PUMP3_A, HIGH);
      mcp2.digitalWrite(PUMP3_B, LOW);
    }else if(dir == reverse){
      mcp2.digitalWrite(PUMP3_A, LOW);
      mcp2.digitalWrite(PUMP3_B, HIGH);
    }else if(dir == halt){
      mcp2.digitalWrite(PUMP3_A, LOW);
      mcp2.digitalWrite(PUMP3_B, LOW);
    }
  }
  delay (1000);
}


void moveLiquid(int experiment, int origin, int target, float liquid_volume)
{
  //experiment ONE_Enyzme Part

  if (experiment == 1 && origin == 0)
  {
    switch_conn_pin(BASEBD_J10_PIN2, LOW); //Experiment 1 valveA, block enzyme
    Serial.println("_E1 move from e_buffer");
  //  saveExperimentalLog("_E1_move from e_buffer");
  }

  if (experiment == 1 && origin == 1)
  {
    switch_conn_pin(BASEBD_J10_PIN2, HIGH); //Experiment 1 valveA, allow enzyme
    Serial.println("_E1 move from enzyme");
  //  saveExperimentalLog("_E1_move from enzyme");
  }

  if (experiment == 1 && target == 2)
  {
    switch_conn_pin(BASEBD_J9_PIN2, HIGH); //Experiment 1 valveB high, waste line open
    int move_pulse = liquid_volume / 25; //1ml = 1000uL and the pump moves 25uL at a time
    Serial.println("_E1 move to chamberA");
  //  saveExperimentalLog("_E1_move to chamberA " + move_pulse * 25 + "uL");
    for (int i = 0; i <= move_pulse; i++) {
      switch_conn_pin(BASEBD_J10_PIN4, HIGH); //Experiment 1 pumpA
      digitalWrite(LED, HIGH);
      delay(200);
      switch_conn_pin(BASEBD_J10_PIN4, LOW); //Experiment 1 pumpA
      digitalWrite(LED, LOW);
      delay(200);
      Serial.println( i * 25); //print out the moving volume
    }
    switch_conn_pin(BASEBD_J10_PIN2, LOW); //Reset eperiment 1 valveA so enzyme is blocked
  }
/* Uncomment and edit line above switch_conn_pin(BASEBD_J9_PIN2, HIGH); to LOW
 if we want to control chamberA and waste flow
  if (experiment == 1 && target == 0)
  {
    switch_conn_pin(BASEBD_J9_PIN2, HIGH); //Experiment 2 valveB high, go to waste
    int move_pulse = liquid_volume / 25; //1ml = 1000uL and the pump moves 25uL at a time
    Serial.println("move to waste");
    saveExperimentalLog("_move to waste " + move_pulse * 25 + "uL");
    for (int i = 0; i <= move_pulse; i++) {
      switch_conn_pin(BASEBD_J10_PIN4, HIGH); //Experiment 2 pumpA
      digitalWrite(LED, HIGH);
      delay(200);
      switch_conn_pin(BASEBD_J10_PIN4, LOW); //Experiment 2 pumpA
      digitalWrite(LED, LOW);
      delay(200);
      Serial.println( i * 25);
    }
    switch_conn_pin(BASEBD_J10_PIN2, LOW); //Reset experiment 2 valveA so enzyme is blocked
  }
*/
//experiment One_BioCell Part
  if (experiment == 1 && origin == 3 && target == 4)
  {
    int move_pulse = liquid_volume / 25; //1ml = 1000uL and the pump moves 25uL at a time
    Serial.println("_E1 media move to chamberB");
  //  saveExperimentalLog("_E1_media_move to chamberB " + move_pulse * 25 + "uL");
    for (int i = 0; i <= move_pulse; i++) {
      switch_conn_pin(BASEBD_J9_PIN4, HIGH); //Experiment 1 pumpB
      digitalWrite(LED, HIGH);
      delay(200);
      switch_conn_pin(BASEBD_J9_PIN4, LOW); //Experiment 1 pumpB
      digitalWrite(LED, LOW);
      delay(200);
      Serial.println( i * 25); //print out the moving volume
    }
  //  switch_conn_pin(BASEBD_J9_PIN2, LOW); //Reset experiment 1 valveB to NC
  }

  //experimentTWO, Enzyme

  if (experiment == 2 && origin == 0)
  {
    switch_conn_pin(BASEBD_J12_PIN2, LOW); //Experiment 2 valveA, block enzyme
    Serial.println("_E2 move from e_buffer");
  //  saveExperimentalLog("_E2_move from e_buffer");
  }

  if (experiment == 2 && origin == 1)
  {
    switch_conn_pin(BASEBD_J12_PIN2, HIGH); //Experiment 2 valveA, allow enzyme
    Serial.println("_E2 move from Enzyme");
  //  saveExperimentalLog("_E2_move from enzyme");
  }

  if (experiment == 2 && target == 2)
  {
    switch_conn_pin(BASEBD_J11_PIN2, HIGH); //Experiment 2 valveB high, waste line open
    int move_pulse = liquid_volume / 25; //1ml = 1000uL and the pump moves 25uL at a time
    Serial.println("_E2 move to chamberA");
  //  saveExperimentalLog("_E2_move to chamberA " + move_pulse * 25 + "uL");
    for (int i = 0; i <= move_pulse; i++) {
      switch_conn_pin(BASEBD_J12_PIN4, HIGH); //Experiment 2 pumpA
      digitalWrite(LED, HIGH);
      delay(200);
      switch_conn_pin(BASEBD_J12_PIN4, LOW); //Experiment 2 pumpA
      digitalWrite(LED, LOW);
      delay(200);
      Serial.println( i * 25);
    }
    switch_conn_pin(BASEBD_J12_PIN2, LOW); //Reset experiment 1 valveA so enzyme is blocked
  }
/* Uncomment and edit line above switch_conn_pin(BASEBD_J11_PIN2, HIGH); to LOW
if we want to control chamberA and waste flow
  if (experiment == 2 && target == 0)
  {
    switch_conn_pin(BASEBD_J11_PIN2, HIGH); //Experiment 2 valveB high, go to waste
    int move_pulse = liquid_volume / 25; //1ml = 1000uL and the pump moves 25uL at a time
    Serial.println("move to waste");
    saveExperimentalLog("_move to waste " + move_pulse * 25 + "uL");
    for (int i = 0; i <= move_pulse; i++) {
      switch_conn_pin(BASEBD_J12_PIN4, HIGH); //Experiment 2 pumpA
      digitalWrite(LED, HIGH);
      delay(200);
      switch_conn_pin(BASEBD_J12_PIN4, LOW); //Experiment 2 pumpA
      digitalWrite(LED, LOW);
      delay(200);
      Serial.println( i * 25);
    }
    switch_conn_pin(BASEBD_J12_PIN2, LOW); //Reset xperiment 2 valveA so enzyme is blocked
  }
*/

  //experimentTWO, Microbe

  if (experiment == 2 && origin == 3 && target == 4)
   {
      int move_pulse = liquid_volume / 25; //1ml = 1000uL and the pump moves 35uL at a time
      Serial.println("_E2 media move to chamberB");
   //   saveExperimentalLog("_E2_media_move to chamberB " + move_pulse * 25 + "uL");
      for (int i = 0; i <= move_pulse; i++){
      switch_conn_pin(BASEBD_J11_PIN4, HIGH); //Experiment 2 pumpB
      digitalWrite(LED, HIGH);
      delay(200);
      switch_conn_pin(BASEBD_J11_PIN4, LOW); //Experiment 2 pumpB
      digitalWrite(LED, LOW);
      delay(200);
      Serial.println( i * 25);
      }
    }
}

void switchCollection(int experiment, int bag)
{
  if (stop_move == 0){

    //experiment one collection
   if (experiment == 1 && bag == 0)
  {
    switch_conn_pin(BASEBD_J5_PIN4, LOW); //Experiment 1 waste V6
    Serial.println("open waste bag");
 //   experimenta_log = experimenta_log + now() + "_opem waste bag,";
  }
  if (experiment == 1 && bag == 1)
  {
    switch_conn_pin(BASEBD_J5_PIN4, HIGH); //NOT V6
    switch_conn_pin(BASEBD_J5_PIN2, LOW); //Experiment 1 preservativeOne V5
    Serial.println("open preservativeOne bag");
  //  experimenta_log = experimenta_log + now() + "_open preservativeOne bag,";
  }
  if (experiment == 1 && bag == 2)
  {
    switch_conn_pin(BASEBD_J5_PIN4, HIGH); //NOT V6
    switch_conn_pin(BASEBD_J5_PIN2, HIGH); //NOT V5
    switch_conn_pin(BASEBD_J3_PIN4, LOW); ////Experiment 1 preservativeTwo V4
    Serial.println("open preservativeTwo bag");
 //   experimenta_log = experimenta_log + now() + "_open preservativeTwo bag,";
  }
    if (experiment == 1 && bag == 3)
  {
    switch_conn_pin(BASEBD_J5_PIN4, HIGH); //NOT V6
    switch_conn_pin(BASEBD_J5_PIN2, HIGH); //NOT V5
    switch_conn_pin(BASEBD_J3_PIN4, HIGH); //NOT V4
    switch_conn_pin(BASEBD_J3_PIN2, LOW); //Experiment 1 preservativeThree V3
    Serial.println("open preservativeThree bag");
 //   experimenta_log = experimenta_log + now() + "_open preservativeThree bag,";
  }
    if (experiment == 1 && bag == 4)
  {
    switch_conn_pin(BASEBD_J5_PIN4, HIGH); //NOT V6
    switch_conn_pin(BASEBD_J5_PIN2, HIGH); //NOT V5
    switch_conn_pin(BASEBD_J3_PIN4, HIGH); //NOT V4
    switch_conn_pin(BASEBD_J3_PIN2, HIGH); //NOT V3
    switch_conn_pin(BASEBD_J1_PIN4, LOW); //Experiment 1 preservativeFour V2
    Serial.println("open preservativeFour bag");
 //   experimenta_log = experimenta_log + now() + "_open preservativeFour bag,";
  }
  
  //experiment two collection
  
if (experiment == 2 && bag == 0)
  {
    switch_conn_pin(BASEBD_J2_PIN2, LOW); //Experiment 2 waste V7 
    Serial.println("open waste bag");
   // experimenta_log = experimenta_log + now() + "_opem waste bag,";
  }
  if (experiment == 2 && bag == 1)
  {
    switch_conn_pin(BASEBD_J2_PIN2, HIGH); //NOT V7
    switch_conn_pin(BASEBD_J2_PIN4, LOW); //Experiment 2 preservativeOne V8
    Serial.println("open preservativeOne bag");
   // experimenta_log = experimenta_log + now() + "_open preservativeOne bag,";
  }
  if (experiment == 2 && bag == 2)
  {
    switch_conn_pin(BASEBD_J2_PIN2, HIGH); //NOT V7
    switch_conn_pin(BASEBD_J2_PIN4, HIGH); //NOT V8
    switch_conn_pin(BASEBD_J4_PIN2, LOW); ////Experiment 2 preservativeTwo V9
    Serial.println("open preservativeTwo bag");
  //  experimenta_log = experimenta_log + now() + "_open preservativeTwo bag,";
  }
  if (experiment == 2 && bag == 3)
  {
    switch_conn_pin(BASEBD_J2_PIN2, HIGH); //NOT V7
    switch_conn_pin(BASEBD_J2_PIN4, HIGH); //NOT V8
    switch_conn_pin(BASEBD_J4_PIN2, HIGH); //NOT V9
    switch_conn_pin(BASEBD_J4_PIN4, LOW); //Experiment 2 preservativeThree V10
    Serial.println("open preservativeThree bag");
  //  experimenta_log = experimenta_log + now() + "_open preservativeThree bag,";
  }
  if (experiment == 2 && bag == 4)
  {
    switch_conn_pin(BASEBD_J2_PIN2, HIGH); //NOT V7
    switch_conn_pin(BASEBD_J2_PIN4, HIGH); //NOT V8
    switch_conn_pin(BASEBD_J4_PIN2, HIGH); //NOT V9
    switch_conn_pin(BASEBD_J4_PIN4, HIGH); //NOT V10
    switch_conn_pin(BASEBD_J6_PIN2, LOW); //Experiment 2 preservativeFour V11
    Serial.println("open preservativeFour bag");
  //  experimenta_log = experimenta_log + now() + "_open preservativeFour bag,";
  }
  }   
  }

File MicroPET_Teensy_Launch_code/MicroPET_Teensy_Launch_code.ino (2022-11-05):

/***************************************************************************
  Base Board Connection:
  E1VA + E1PA - J10
  E1VB + E1PB - J09
  E2VA + E2PA - J12
  E2VB + E2PB - J11
  the valve board connector J1-6 are the same on the base board

 ***************************************************************************/
#include <TimeLib.h>
#include <TimeAlarms.h>
#include <Wire.h>
#include <SPI.h>
#include <Adafruit_Sensor.h>
#include <Adafruit_BME280.h>
#include <Adafruit_AS726x.h>
#include <Adafruit_MCP23X17.h>
#include "RTClib.h"

/* Experiment Prototypes and supporting defines */
#define TOTAL_EXPERIMENTS 26
void day_1();
void day_2();
void day_3();
void day_4();
void day_5();
void day_6();
void day_7();
void day_8();
void day_9();
void day_10();
void day_11();
void day_12();
void day_13();
void day_14();
void day_15();
void day_16();
void day_17();
void day_18();
void day_19();
void day_20();
void day_21();
void day_22();
void day_23();
void day_24();
void day_25();
void day_26();

void (*experimentArray[TOTAL_EXPERIMENTS])() = {day_1, day_2, day_3, day_4, day_5, day_6, day_7, day_8, day_9, day_10, day_11, day_12, day_13, day_14, day_15, day_16, day_17, day_18, day_19, day_20, day_21, day_22, day_23, day_24, day_25, day_26};
//Teensey 4.1 - SCL 19 - yellow /SDA 18 - blue

#define BME_SCK 13
#define BME_MISO 12
#define BME_MOSI 11
#define BME_CS 10
#define SEALEVELPRESSURE_HPA (1013.25)

RTC_PCF8523 rtc;

uint16_t experimentIndex = 0;

// Native I2C address of the mux
#define MUX_ADDR    0x70
// Native I2C address of both AS7262 sensors
#define AS7262_ADDR 0x49
// Native I2C address of both BME280 sensors
#define BME280_ADDR 0x76
// Sensor positions on the mux
#define AS7262_SENSOR1  3
#define AS7262_SENSOR2  0
#define BME280_SENSOR1  2
#define BME280_SENSOR2  1

Adafruit_BME280 bme;
Adafruit_AS726x ams;

unsigned long delayTime;
#define SEALEVELPRESSURE_HPA (1013.25)
uint16_t sensorValues[AS726x_NUM_CHANNELS];

//SD Card
#include <SD.h>
#include <SPI.h>

typedef struct {
  byte experimentStarted;
  time_t epoch;
  byte testDay;
  byte testDayComplete;
  byte testInterval;
} systemStateStruct;

File myFile;
File expLogFile;
const int chipSelect = BUILTIN_SDCARD;
const int ledPin = 5;

systemStateStruct systemStateStructVar = {0, 0, 0, 0};

//IO ports

#define MCP_ADDR0 0x20  // IC5 on base board
#define MCP_ADDR1 0x21  // IC4 on base board
#define MCP_ADDR2 0x22  // IC1 on sensor board

enum motion { forward, reverse, halt };
#define PUMP1_A 8
#define PUMP1_B 9
#define PUMP2_A 10
#define PUMP2_B 11
#define PUMP3_A 12
#define PUMP3_B 13

#define LED 13

// Double check these pin assignments
#define GPA0 0
#define GPA1 1
#define GPA2 2
#define GPA3 3
#define GPA4 4
#define GPA5 5
#define GPA6 6
#define GPA7 7

#define GPB0 8
#define GPB1 9
#define GPB2 10
#define GPB3 11
#define GPB4 12
#define GPB5 13
#define GPB6 14
#define GPB7 15

#define experimentOne 1
#define experimentTwo 2

#define e_buffer 0
#define enzyme 1
#define chamberA 2
#define media 3
#define chamberB 4

#define waste 0
#define preservativeOne 1
#define preservativeTwo 2
#define preservativeThree 3
#define preservativeFour 4
#define preservativeFive 5


Adafruit_MCP23X17 mcp0;
Adafruit_MCP23X17 mcp1;
Adafruit_MCP23X17 mcp2;

typedef enum {
  // MCP0 - IC5 on base board
  BASEBD_J4_PIN2 = 0,
  BASEBD_J4_PIN4,
  BASEBD_J3_PIN2,
  BASEBD_J3_PIN4,
  BASEBD_J2_PIN2,
  BASEBD_J2_PIN4,
  BASEBD_J1_PIN2,
  BASEBD_J1_PIN4,
  BASEBD_J5_PIN2,
  BASEBD_J5_PIN4,
  BASEBD_J6_PIN2,
  BASEBD_J6_PIN4,
  BASEBD_J7_PIN2,
  BASEBD_J7_PIN4,
  BASEBD_J8_PIN2,
  BASEBD_J8_PIN4,

  // MCP1 - IC4 on base board
  BASEBD_J12_PIN2,
  BASEBD_J12_PIN4,
  BASEBD_J11_PIN2,
  BASEBD_J11_PIN4,
  BASEBD_J10_PIN2,
  BASEBD_J10_PIN4,
  BASEBD_J9_PIN2,
  BASEBD_J9_PIN4,

  //MCP2 - IC1 on sensor board
  SENSEBD_J2_PIN1,
  SENSEBD_J2_PIN2,
  SENSEBD_J2_PIN3,
  SENSEBD_J2_PIN4,
  SENSEBD_J3_PIN1,
  SENSEBD_J3_PIN2
} CONN_PIN_T; // Connector and Pin type

#define MCP1_PIN_OFFSET 16
#define MCP2_PIN_OFFSET 16

/****************************************/

boolean switch_conn_pin(CONN_PIN_T conn_pin, byte level)
{
  if ((level != HIGH) && (level != LOW)) {
    return false;
  }

  if (conn_pin <= BASEBD_J8_PIN4) {
    mcp0.digitalWrite(conn_pin, level);
  } else if (conn_pin <= BASEBD_J9_PIN4) {
    mcp1.digitalWrite((conn_pin - MCP1_PIN_OFFSET), level);
  } else if (conn_pin <= SENSEBD_J3_PIN2) {
    mcp2.digitalWrite((conn_pin - MCP2_PIN_OFFSET), level);
  } else {
    return false;
  }

  return true;
}


String experimenta_log = "";
unsigned int whichsensor = 0;

#define SECONDS_IN_DAY 86400
//#define DELAY_SECONDS_PER_EXPERIMENT SECONDS_IN_DAY
#define DELAY_SECONDS_PER_EXPERIMENT 120 // 2 mins for the functional testing
#define SERIAL_TIMEOUT 10000 //milliseconds

const unsigned int MAX_MESSAGE_LENGTH = 12;
bool systemState = 0;

//AlarmID_t Alarm_Day1_ID;
//AlarmID_t Alarm_Day2_ID;
//AlarmID_t Alarm_Day3_ID;
//AlarmID_t Alarm_Day4_ID;
//AlarmID_t Alarm_Day5_ID;
//AlarmID_t Alarm_Day6_ID;
//AlarmID_t Alarm_Day7_ID;
//AlarmID_t Alarm_Day8_ID;
//AlarmID_t Alarm_Day9_ID;

// Function to select a sensor
void tcaselect(uint8_t sensor_addr) {
  Wire.beginTransmission(MUX_ADDR);
  Wire.write(1 << sensor_addr);
  Wire.endTransmission();
}
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

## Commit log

2022-03-03 added code in rehersal sketch to generate a logFile that tracks where the experiment is in execution in case power failure occurs.
    [MicroPET_DressRehearsal_202202.ino]
2022-03-13 Fix myFile function/add mills to the table header
    [MicroPET_DressRehearsal_202202.ino]
2022-03-14 Add "Found RTC"
    - Add "time is now" to sensor taking process.
2022-03-24 Add debugger code for sensor
2022-03-25 fixed PatPat's debug code to read temperature-calibrated light readings vs the raw ones
    [Teensy_sensor_debug.ino]
2022-04-18 added code to receover from power failure in between experiments
    [MicroPET_DressRehearsal_202202.ino]
2022-04-18 added call to recoverSystemStart function when a power failure is detected
    [MicroPET_DressRehearsal_202202.ino]
2022-04-18 fixed a comment for the power failure function
    [MicroPET_DressRehearsal_202202.ino]
2022-04-28 multiple sensor line integration + 202202 Dress Rehearsal version restored
    multiple sensor line integration + 202202 Dress Rehearsal version restored.
2022-04-28 corrected git merge failure
    [MicroPET_DressRehearsal_202204.ino]
2022-05-16 added function to control motors on sensor breakout (i.e., motorSensorBrdCtrl)
2022-06-13 sensor code edited
2022-06-13 Pat: Add pump control with volume
2022-06-15 Fix the date recorded in the Log
    [MicroPET_DressRehearsal_202204.ino]
2022-11-03 adding revival pump function to move_liquid
2022-11-05 fixed issue where too many timers created at once
2022-11-05 Revival motor fixed
2022-11-05 sensor fixed
2024-08-30 Upload all the files/update readme
    [BioCell Final Print v5.stl, BioCell LED holder v5.stl, MicroPET_base_enclosure_01 v2.stl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]
